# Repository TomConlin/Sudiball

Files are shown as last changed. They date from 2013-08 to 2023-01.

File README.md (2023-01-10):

Sudiball
========
# Sudiball
## Skeletal ball and socket  
### It's like a ball but less.   

To play with the models yourself you will need to  
install a recent __stable__ version of OpenSCAD  
(You may need to get a recent version from <http://www.openscad.org/>)

I am focusing this software on easily built "standard" versions  
(where the planes intersect at right angles in the center of the ball).   
To facilitate visual experimentation prior to generating 2D or 3D files,   
the OpenSCAD scripts are divided into four modules.

__sudiconfig.scad__: Where you will edit parameters (use any text editor)   
__sudiview.scad__:	 Open with OpenSCAD to see changes from parameters edited & save 3D.  
__sudigen.scad__:	 Open with OpenSCAD to generate 2D parts seen in sudiview  
__sudilib.scad__:	Common routines used by both sudiview & sudigen.   

Workflow is: with all four files in the same directory:  
1.  open the _sudiconfig.scad_ file in your favorite text editor  
  (you can also use OpenSCAD as your editor but will need to switch files more  
2.  open __sudiview.scad__ in OpenSCAD and have it render (hit F5)  
3.  Edit the _sudiconfig.scad_ file to suit your needs  
4.  Hit F5 to render your changes in the OpenScad window running sudiview.scad_  
5.  Rinse and repeat the previous two steps to your hearts content  
6.  For 3D files just choose the format you want (.stl) and __Export__ it.  
7.  For 2D files of one flat sheet use __sudigen.scad__ and read instructions.  

------------------------------------------------------------------------
For more information see:
  
- My page with other ATM related
https://ix.cs.uoregon.edu/~tomc/Hobbies/Astronomy/ATM/index.html  
 
- A short informal paper
http://ix.cs.uoregon.edu/~tomc/Hobbies/Astronomy/ATM/SudiBall.pdf

- Initial set of vector files (circa 2013)  
[SVG,DXF,PDF](vector_files/)  
[Initial OpenSCAD SudiBall Template](Mark_I/sudiball_template.scad/)

------------------------------------------------------------------------
Occasional Updates with newer further down the page  
--2013 Jul

In the spirit of moving from the theoretical "you can design anything you want" 
to the more practical -- this is the simplest Sudiball to build with everyday tools and materials. 

CAD drawings and print files of my first generic Sudiball are in the [Vector Files](/vector_files/) directory. 
There are two sizes of vector drawing and four formats in the
Both are designed to use 3/4" material. 
So far, the 24" has been scaled in half and used with 3/8" material 
and to a third to use 1/4" material. 

The Postscript can be printed on paper glued to whatever and cut out for quick tests 
the DXF may need some cleanup before feeding to a machine, i.e cross-hairs removed.
The important part here is the slots are just 90 degree cuts 
and cutting the entire profile at 90 degrees does not interfere 
with making the compound curve on the runners as a separate operation. 
This means the profiles may be cut with a laser, waterjet, CNC router, milling machine 
or by hand with a router or saw.

The compound curve on the runners of a two foot diameter Sudiball with a 3/4" thick edge 
is under six thousandths of an inch, since the square edge is tangent to the sphere. 
This means just breaking the edge with sandpaper does a pretty good job of forming the desired curve.
i.e. Sticking adhesive back sandpaper to the ground ring and swirling it about is enough.

--------------------------------------------------------------------------------

--2017 March  
A couple of incremental update notes.  
First regarding a base which can be a simple ring.  
The SudiBall must contact the ring in at least three places which limits the
diameter of the supporting ring to be not smaller than
the height of the triangle formed by the intersecting runners.
(height is measured from the center of the base to the apex of an equlateral triangle)  
This give a rule of thumb of the diameter of the contact patch on
the support ring not less than 61.25% of the SudiBall diameter.

If you care where the 61.25% comes from,  
the length of a chord with 90 deg separation is:  
`2 *sin (90/ 2 ) * r`

three of those chords come together as a equilateral triangle  
the height of an equilateral triangle is  
`sin(60) * length of a side`  
since we want a precentage of a unit diameter and not of a unit radius
we can drop the leading `2 *`

`sin(45) ×sin(60)  = 0.612372436`  
`0.612372436 * 100 = 61.25%`
 
------------------------------------------------------------------------------
second note:   
It is easy to unedrestimate the lateral forces in play which to tend to distort
the ring from circular to a trifoil or warped from a plane.
Even small distortions will cause a _TIC!_ when a runner contacts the support ring broadside.

Two approaches to mitigate the _TIC!_.  
- Use a stronger ring support.  
- Ease the approach onto the support.  

The first needs whatever works, the second is geometery.  
If the support surface is flat and nearly _normal_ or _tangent_ to the curve
of the SudiBall it forms little "on ramps" whos easement is related to 
the the width of of the flat surface.  
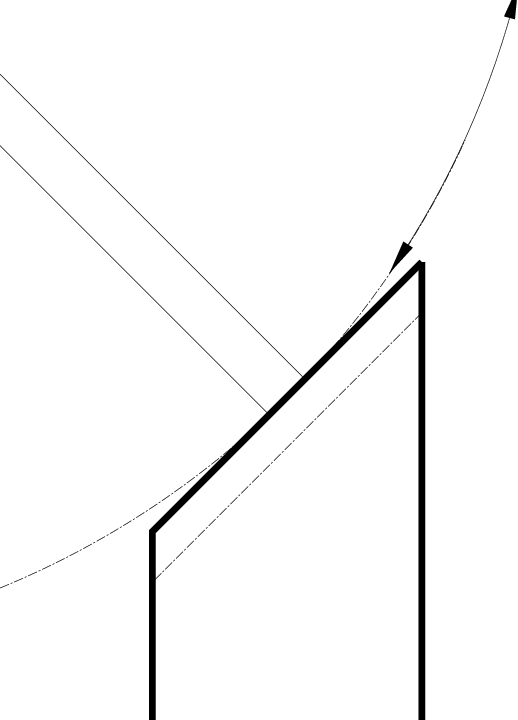
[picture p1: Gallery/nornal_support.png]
conic easement


It also allows covering the support surface with a (_replacable_)   
sheet material i.e. metal or fancy plastics cut into a strip with a [Cone Calculator](https://duckduckgo.com/?q=cone+calculator&ia=web)

With a slightly larger than minimal sized ring for a standard three plane SudiBall  
an off-the-shelf [45-deg router bit](https://duckduckgo.com/?q=45+deg+router+bit+chamfer&iax=1&ia=images)
swung in a [router compass jig](https://duckduckgo.com/?q=router+compass+jig&iar=images&iax=1&ia=images) will chamfer
a nearly normal support surface.  

------------------------------------------------------------------------------

Joining the tips of a sudiball together can be tricky if joinery is not also your day job
but by cutting interlocking fingers into the ends of the runners you get a
simple solid connection called a [fingerjoint](https://en.wikipedia.org/wiki/Finger_joint)  
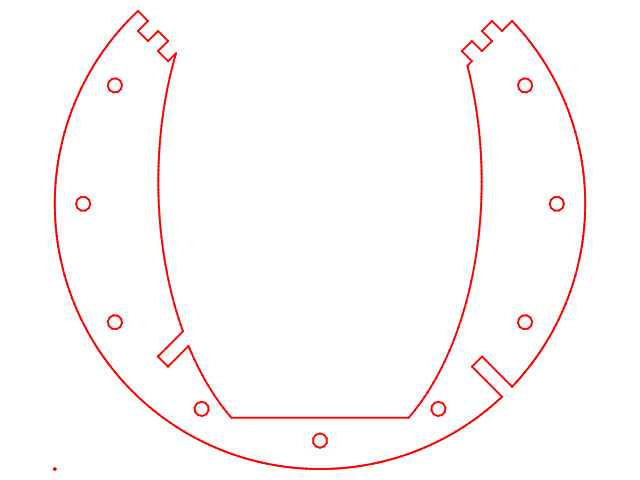
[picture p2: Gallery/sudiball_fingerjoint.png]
fingerjoint
  
(which is especially trivial if you are using  CNC with negligible kerf)

-------------------------------------------------------------------------------
-------------------------------------------------------------------------------

If you have build a SudiBall, please do get in touch,

I have set up a [Rouges Gallery](https://ix.cs.uoregon.edu/~tomc/Hobbies/Astronomy/ATM/SudiBall/RoguesGallery/index.html) and would be happy to show or point your work.

The annotated gallery is currently set up to accept jpeg images  
along with an optional separate simple text (.txt) file per image.  
(same filenames, diferent extensions)

Email sudiball360@gmail.com for more info.

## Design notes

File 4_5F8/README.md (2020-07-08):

There many unloved 4.5" (114mm) f8 Newtonion telescopes out there on rickety tripods. 


Pushed each holliday season then closeted till the garage sale when the novelty of fiddeling with setting it up wears off.  

Now a days they get trumped up with "GoTo" moters for double extra fiddelness and a coresponding disapointment with 
what is charitably, a binocular scale view with poor eye relief and awkward handeling.  

We can't change the optics, but by mounting as a Sudiball we can eliminate fiddeling with the spindley tripod 
and improve the ergomomics for viewing (especially for child sized humans).

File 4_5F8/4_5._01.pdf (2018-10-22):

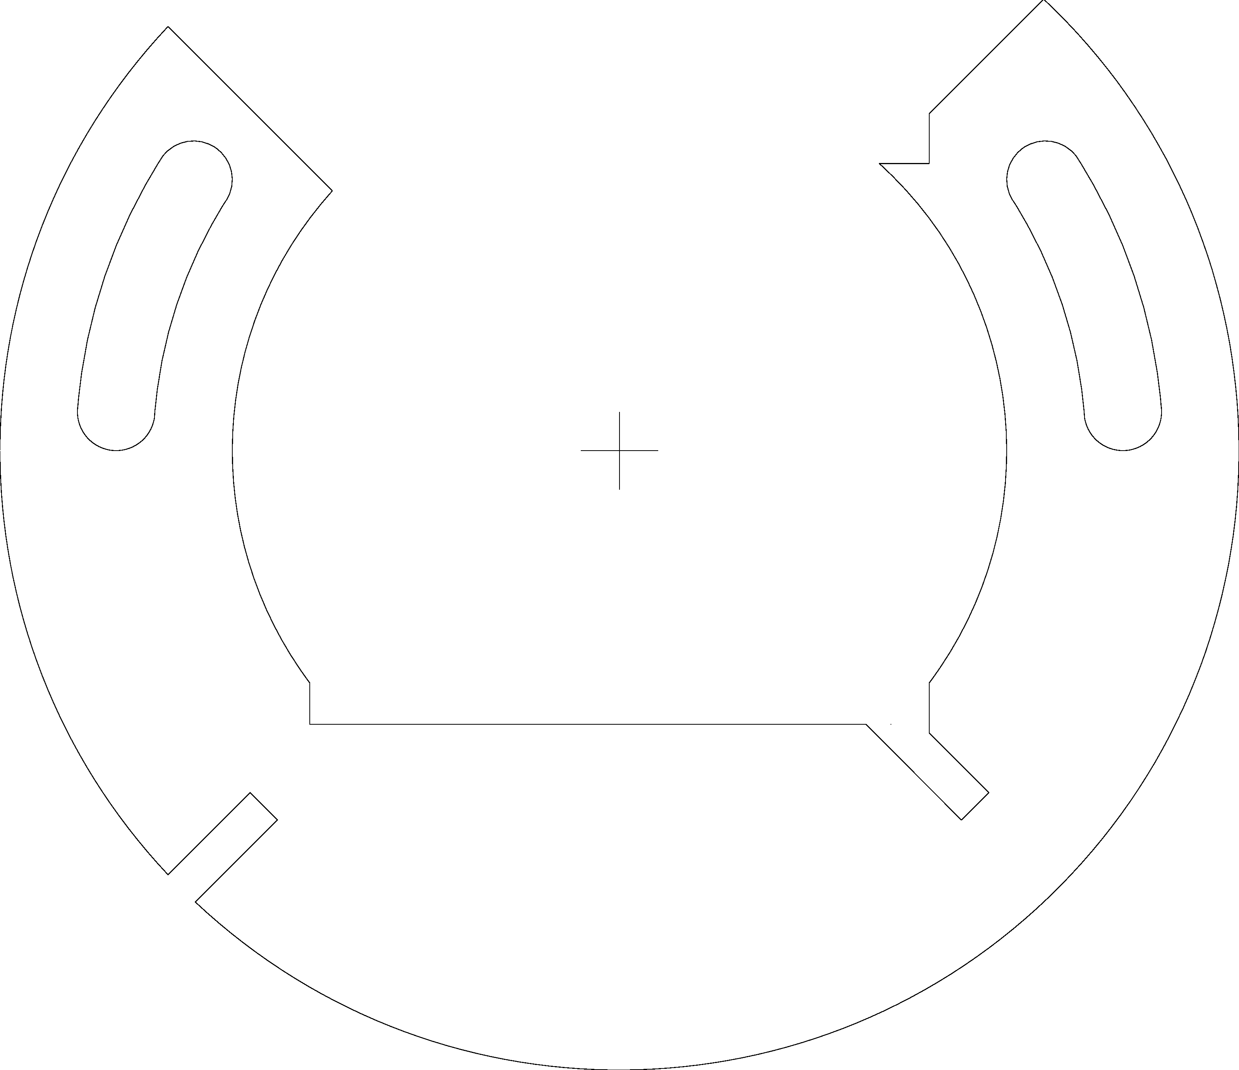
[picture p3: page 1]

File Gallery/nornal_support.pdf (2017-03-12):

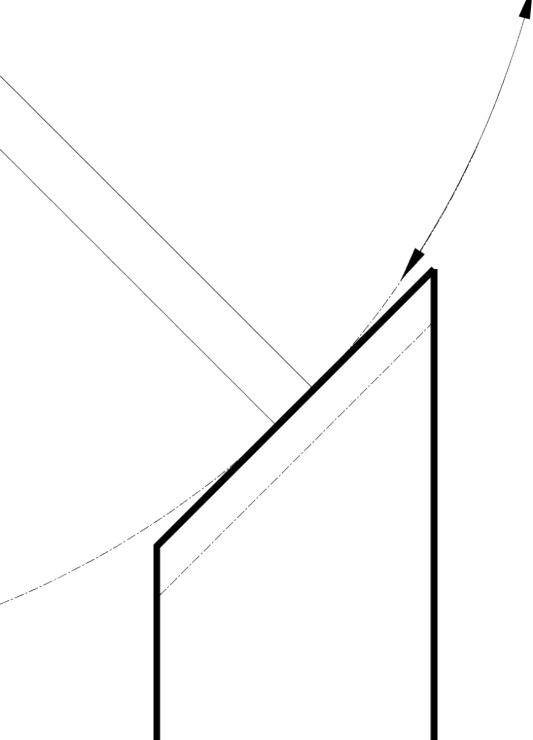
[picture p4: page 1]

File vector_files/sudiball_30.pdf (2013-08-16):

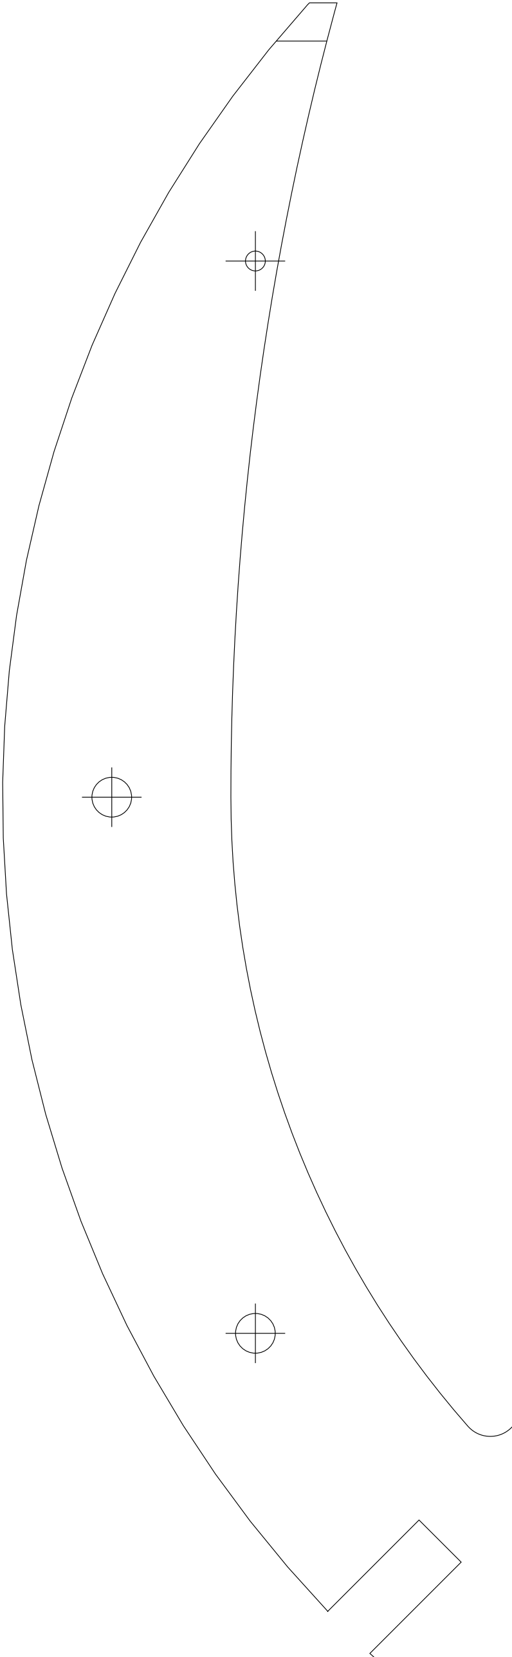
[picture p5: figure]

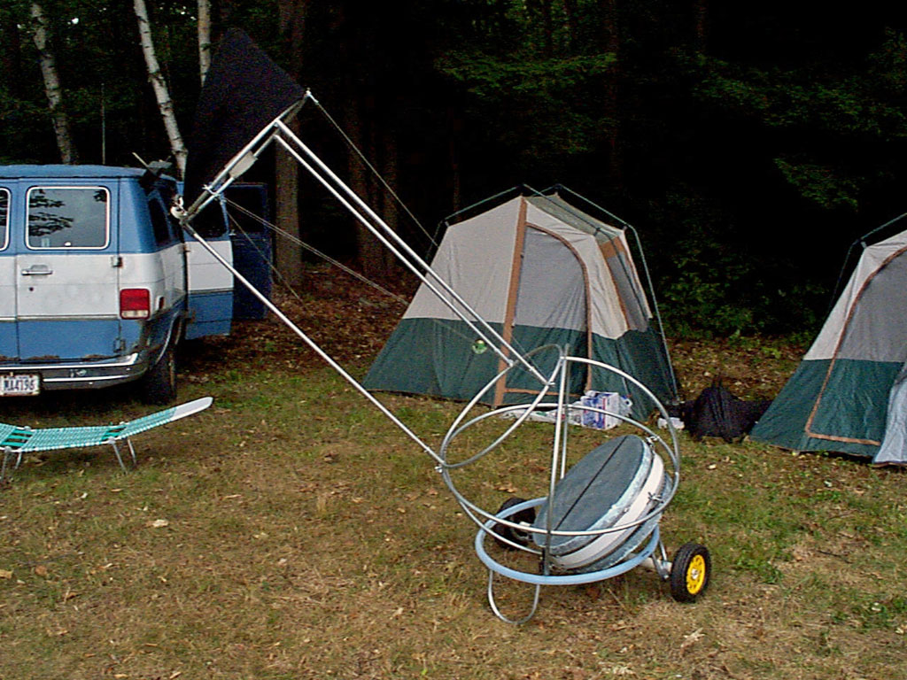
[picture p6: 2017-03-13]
Gallery/Stelafane_1999_via_Pierre_Lemay.jpg

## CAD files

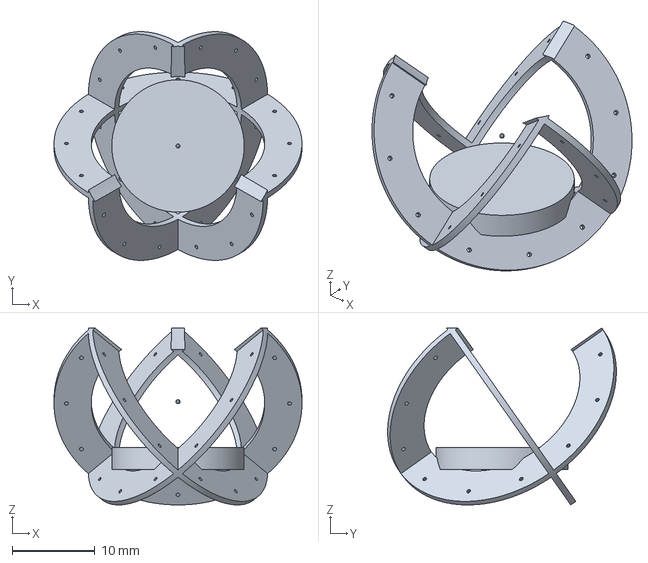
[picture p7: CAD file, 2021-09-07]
16_F4.5/16F4_5.3mf
30.0 x 27.7 x 21.4 mm

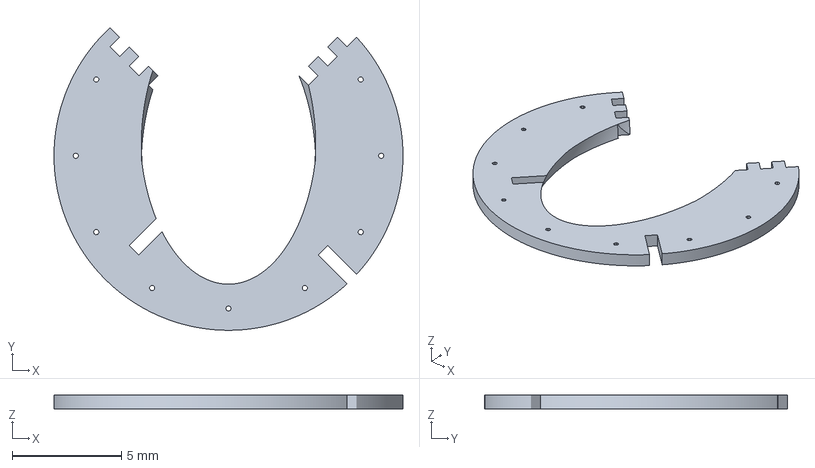
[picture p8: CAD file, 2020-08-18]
4_5F8/gen_panel_section.3mf
16.0 x 13.9 x 0.625 mm

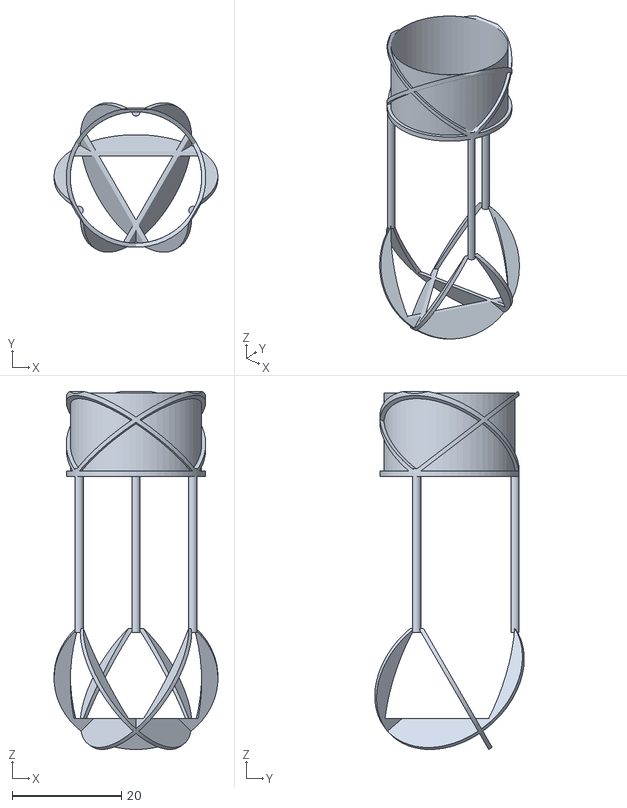
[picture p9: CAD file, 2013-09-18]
OSP_30_2.stl
30.0 x 27.3 x 65.4

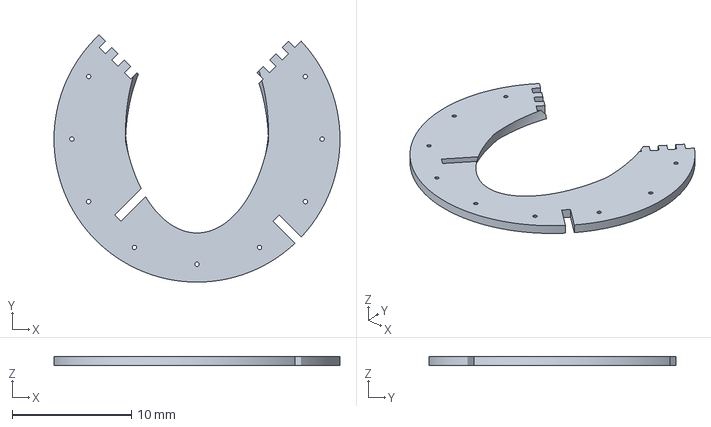
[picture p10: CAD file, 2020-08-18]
sixF8/gen_panel_section.3mf
24.0 x 20.7 x 0.75 mm

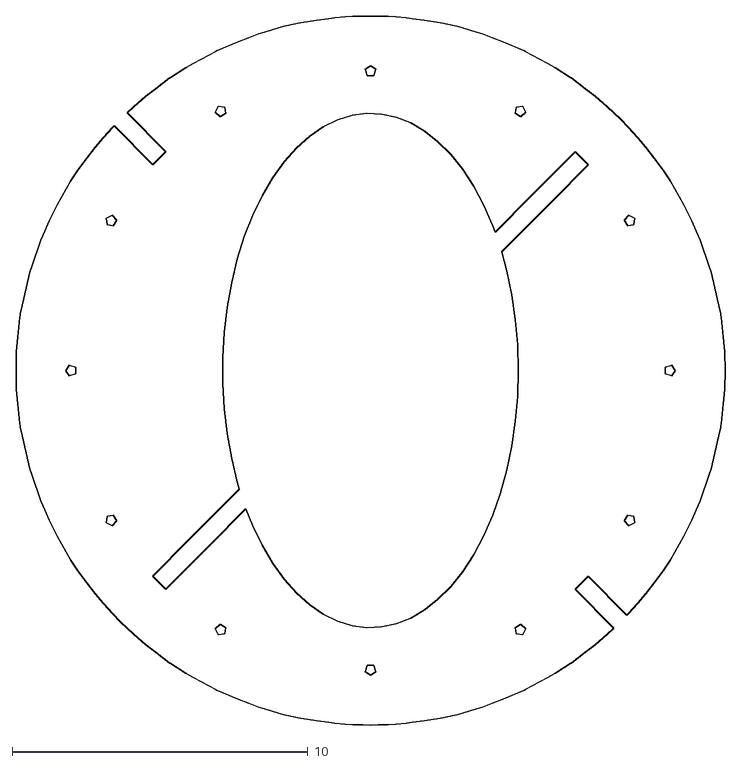
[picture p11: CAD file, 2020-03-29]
TenF4_5/sudigen_10in_path.dxf
24.0 x 24.0

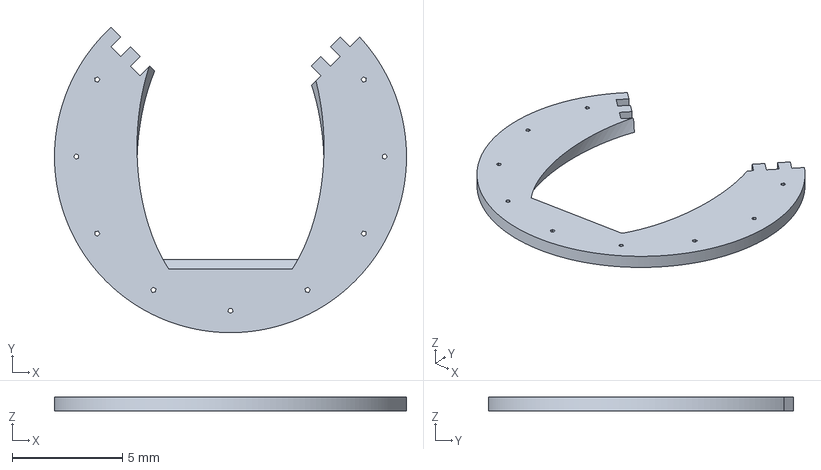
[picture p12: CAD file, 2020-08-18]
Travel_8-F4/travel8f4l_section.3mf
16.0 x 13.9 x 0.625 mm

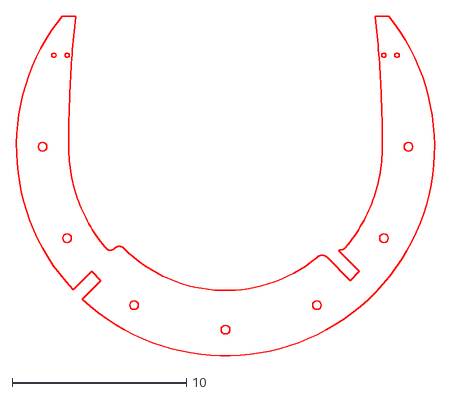
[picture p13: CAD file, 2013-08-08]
vector_files/sudiball_24.dxf
24.0 x 19.5

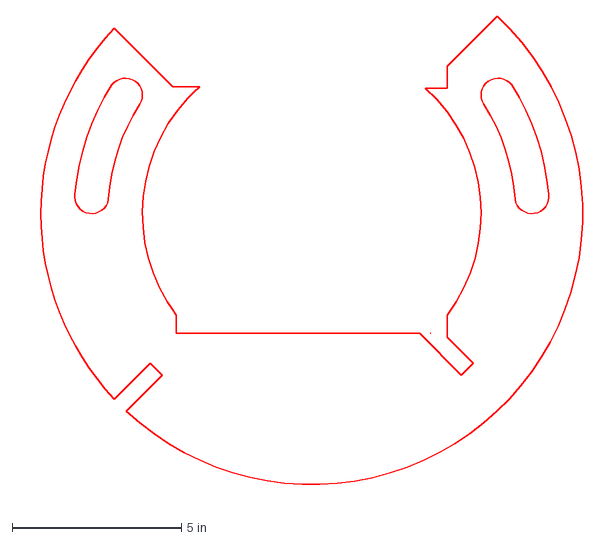
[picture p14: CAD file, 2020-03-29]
4_5F8/4501_resave.dxf
17.2 x 14.3 in

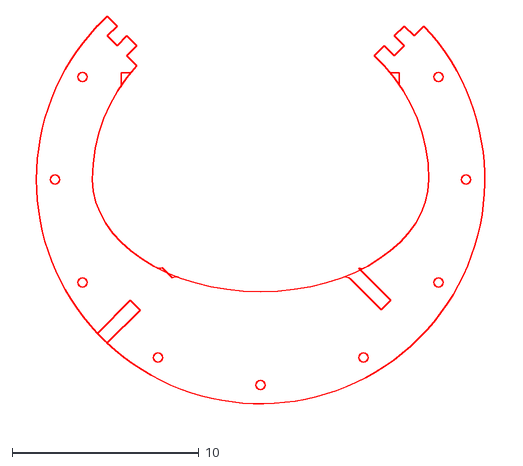
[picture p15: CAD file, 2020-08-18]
sixF8/criterian_tube_holder_print.dxf
26.3 x 21.9

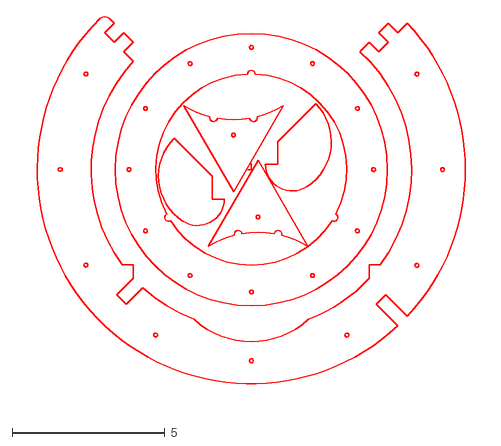
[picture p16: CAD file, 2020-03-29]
TenF4_5/laz1.dxf
15.3 x 12.7

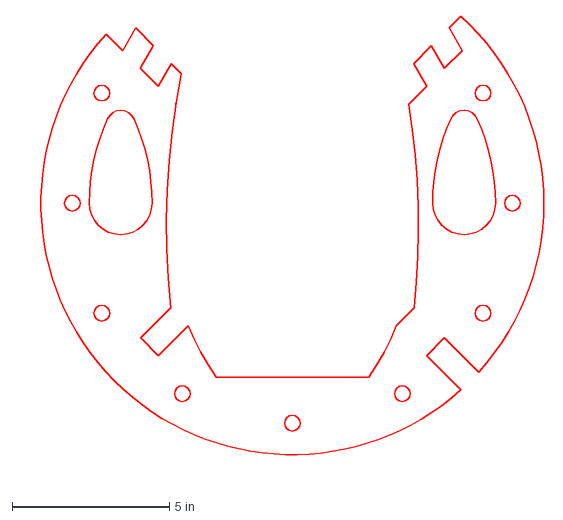
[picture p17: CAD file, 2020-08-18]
Travel_8-F4/#layout3.4.dxf
16.9 x 14.7 in

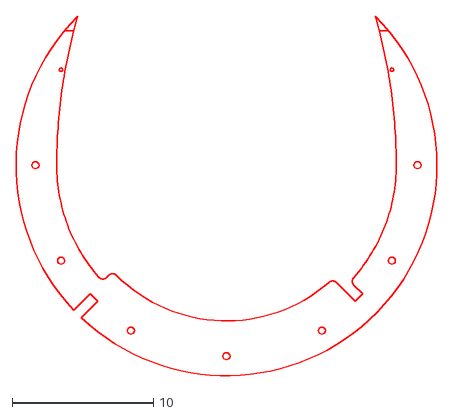
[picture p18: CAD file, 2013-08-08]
vector_files/sudiball_30.dxf
29.7 x 25.4

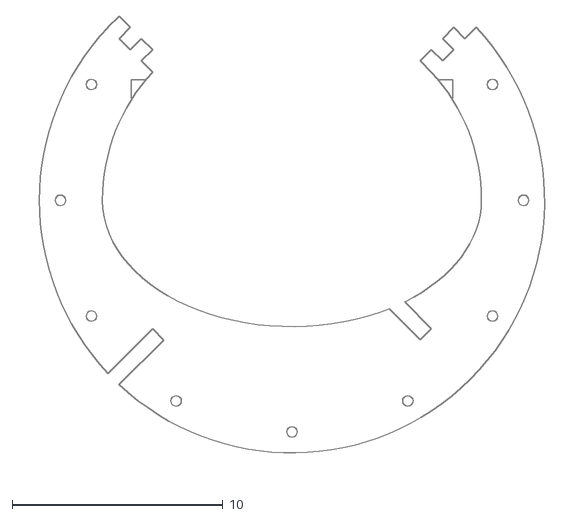
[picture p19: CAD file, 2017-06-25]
sixF8/classic_6in_tube_sudiball_qcad.dxf
26.3 x 21.9

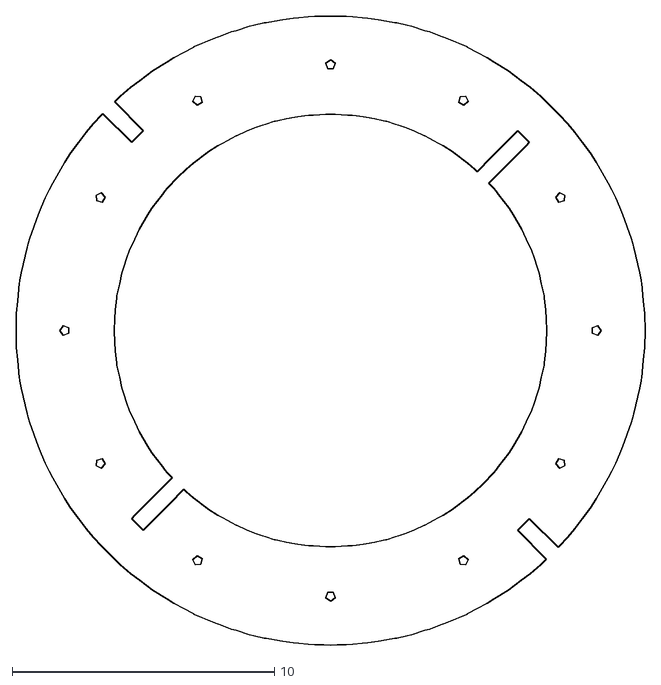
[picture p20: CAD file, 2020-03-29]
TenF4_5/sudigen_6xthick.dxf
24.0 x 24.0

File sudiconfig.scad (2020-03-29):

// SudiConfig
// design parameters to be shared between 3d model generator script
// and the 2D dfx generator script
// KNOWN TO WORK WITH OpenSCAD version 2014.03
// (and seen not working in unstable snapshots)

// bring in the basic helper functions
include <sudilib.scad>;

// magic numbers begin wth '$'
// smaller magic numbers result in slower but smoother curves
// values smaller than .1 are ignored
// make them larger when viewing and smaller when generating if necessary

$fa =	4 ;		   // fragment angle (what looks smooth enough)
$fs =	.5;		// fragment size (using the radius of rouder bit used here)

// mirror amd optical tube assembly (OTA) parameters
ota_id = 8;			// what diameter mirror
F_ratio= 4.0;		// focal ratio (for approximate appearance)

// Sudiball mount design parameters
planes	 =  3;	//  2,[3],4...
tilt	 = 45;	// +/- angles in degrees for the plane

ball_dia = 14;		// what diameter ball to use
thickness = .375;	// sheet material thickness

// hole pattern parameters
// these are holes about the perimeter for fixtures, jigs and whatever
hp_patdia    =	12.5;	// pattern diameter (apx; ball_dia- 4 * thickness)
hp_holedia   =	.375;	// hole diameter
hp_holedepth =	thickness; // hole depth (centered, will add epsilon > 0)
hp_holecount =	12;		// how many holes(would be in full 360 deg)

////////////////////////////////////////////////////////////////////////////////
// derived variables (these should not need to be edited)
intersect =	ball_dia / 2;
ota_ir =	ota_id / 2;
ota_or = ota_ir + thickness;
ball_r =	ball_dia / 2;
delta  =	360 / planes;
centerofrotation = [0,0,intersect];

// to compensate for order of transform operations
relative_tilt =  asin(sin(tilt)) * sin(delta) * 180 / PI;

// may be red herring, but for  45 by 45 
// the above & miter only differ by a half deg
// atan(tan(rot)×cos(tilt))  // miter 
// asin(sin(rot)*sin(tilt))  // bevel

//////////////////////////////////////////////////////////////////////////////
// modules to define shapes used in both sudiview and sudigen

// define the light path clearance to be removed from inside the ball,
// r1 is the light path clearance at the mirror.
// r2 is the clearance some distance above the mirror.
// r2 is not smaller than r1.
// if r2 > r1 then the light path clearance is a cone and 
// the intersection of a cone and inclined plane is a parabola 
// which can be a nice aesthetic.
module lightpath (){
	// the light path won't begin lower in the ball than
	// the dia of the mirror will fit within
    // min height plus whatever is needed to maintain structure or looks.
	translate([0,0,ball_r-sqrt(ball_r*ball_r-ota_ir*ota_ir)+ 3 *thickness])
		cylinder(
			r1 = ota_ir,	 			            // r1 needs to clear the mirror
			r2 = ball_r - 6*thickness,	// r2 can be whatever works for you
			h  = ball_dia - thickness	// h can be whatever works for you
		);
}

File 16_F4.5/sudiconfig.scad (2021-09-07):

// SudiConfig
// design parameters to be shared between 3d model generator script
// and the 2D dfx generator script
// KNOWN TO WORK WITH OpenSCAD version 2014.03
// (and seen not working in unstable snapshots...)
// updated to work in OpenSCAD 2019.05


// bring in the basic helper functions
use <sudilib.scad>;

// magic numbers begin wth '$'
// smaller magic numbers result in SLOWER but smoother curves
// values smaller than .1 are ignored
// make them larger when viewing and smaller when generating if necessary

$fa =	1;		    // fragment angle (what looks smooth enough)
$fs =	.1;		    // fragment size

// mirror amd optical tube assembley (OTA) parameters
ota_id = 16;		// apx what diameter mirror
F_ratio= 4.5;		// focal ratio (for approximate appearance)

// Sudiball mount design parameters
planes	 =  3;	    //  2,[3],4...
tilt	 = 45;	    // +/- angles in degrees for the plane

ball_dia = 30;		// what diameter ball to use
thickness = 0.75;	// sheet material thickness

// hole pattern parameters
// these are holes about the permiter for fixturing
hp_patdia    =	27;	// pattern diameter (apx; ball_dia - 4 * thickness)
hp_holedia   =	.5;	// hole diameter
hp_holedepth =	thickness; // hole depth (centered, will add epsilon > 0)
hp_holecount =	12;		// how many holes (in a full circle)

// derived variables
intersect =	ball_dia / 2;
ota_ir =	ota_id / 2;
ota_or =    ota_ir + 0 ;  //thickness;
ball_r =	ball_dia / 2;
delta  =	360 / planes;
centerofrotation = [0,0,intersect];

//  relative tilt (to horizontal/vertical)
relative_tilt =  sin(tilt) * sin(delta) * 180 / PI;

// i.e. for three planes tilted 45 degrees  
// sin(45) × sin(120) × 180 ÷ 3.1415926535  == 35.0864 degrees
// complement is: 54.9136 degrees


//////////////////////////////////////////////////////////////////////////////
// modules to define shapes used in both sudiview and sudigen

// define the light path clearence to be removed from inside the ball,
module lightpath(){
  // the light path won't begin lower in the ball than
  // the dia of the mirror will fit within

  // min height plus whatever is needed to look right or maintain structure
	translate([0, 0, ball_r-sqrt(ball_r*ball_r - ota_ir*ota_ir) +3*thickness])
		cylinder(
			// r1 needs to clear the mirror @ contact
			r1 = ota_ir,
			// r2 whatever works, not less than r1
			r2 = ota_ir ,
			// h can be whatever works for you
			h  = ball_dia - thickness
		);
}


// define the light path clearence to be removed from inside the ball,
module lightpath2(){
	// the light path won't begin lower in the ball than 
	// the dia of the mirror will fit within
	
	translate([0,0,  ball_r*(1-sin( acos(ota_ir/ball_r) )) + thickness * 6])
		cylinder(
			// r1 needs to clear the mirror @ contact
			r1 = ota_ir, // - 2*thickness,	
			// r2 whatever works, not less than r1 
			r2 = ota_ir,
			// h can be whatever works for you
			h = ball_dia 
		);	
}
///////////////////////////////////////////////////////////////////////////
//
module tiptrim(){
	translate([0, 0, ball_r + thickness/2])
		cylinder(
			r1 = 0,
			r2 = ball_r * 1.414,
			h  = ball_r
		);
}

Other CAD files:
Travel_8-F4/gen_panel_section.3mf
sixF8/classic_6in_tube_sudibal_sagl.dxf
TenF4_5/laz1.1.dxf
4_5F8/sudiconfig.scad
sixF8/sudiconfig.scad
16_F4.5/16F4_5.stl
16_F4.5/sudigen.scad
16_F4.5/sudilib.scad
16_F4.5/sudiview.scad
4_5F8/gen_panel_section.amf
4_5F8/gen_panel_section.scad
4_5F8/gen_panel_section.stl
4_5F8/sudigen.scad
4_5F8/sudiview.scad
Mark_I/sudiball_template.scad
TenF4_5/dxf_import.scad
TenF4_5/freecad_dxf_to_oscad.scad
TenF4_5/sudiconfig.scad
TenF4_5/sudigen.dxf
TenF4_5/sudigen.scad
TenF4_5/sudiview.scad
Travel_8-F4/dxf_import.scad
Travel_8-F4/freecad_dxf_to_oscad.scad
Travel_8-F4/gen_panel_section.amf
Travel_8-F4/gen_panel_section.scad
Travel_8-F4/gen_panel_section.stl
Travel_8-F4/layout2.1.dxf
Travel_8-F4/layout2.2.dxf
Travel_8-F4/layout2.2_flip.dxf
Travel_8-F4/layout2.4.dxf
Travel_8-F4/layout2.4.nc.dxf
Travel_8-F4/layout2_plns.dxf
Travel_8-F4/layout2_plns_cam.dxf
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

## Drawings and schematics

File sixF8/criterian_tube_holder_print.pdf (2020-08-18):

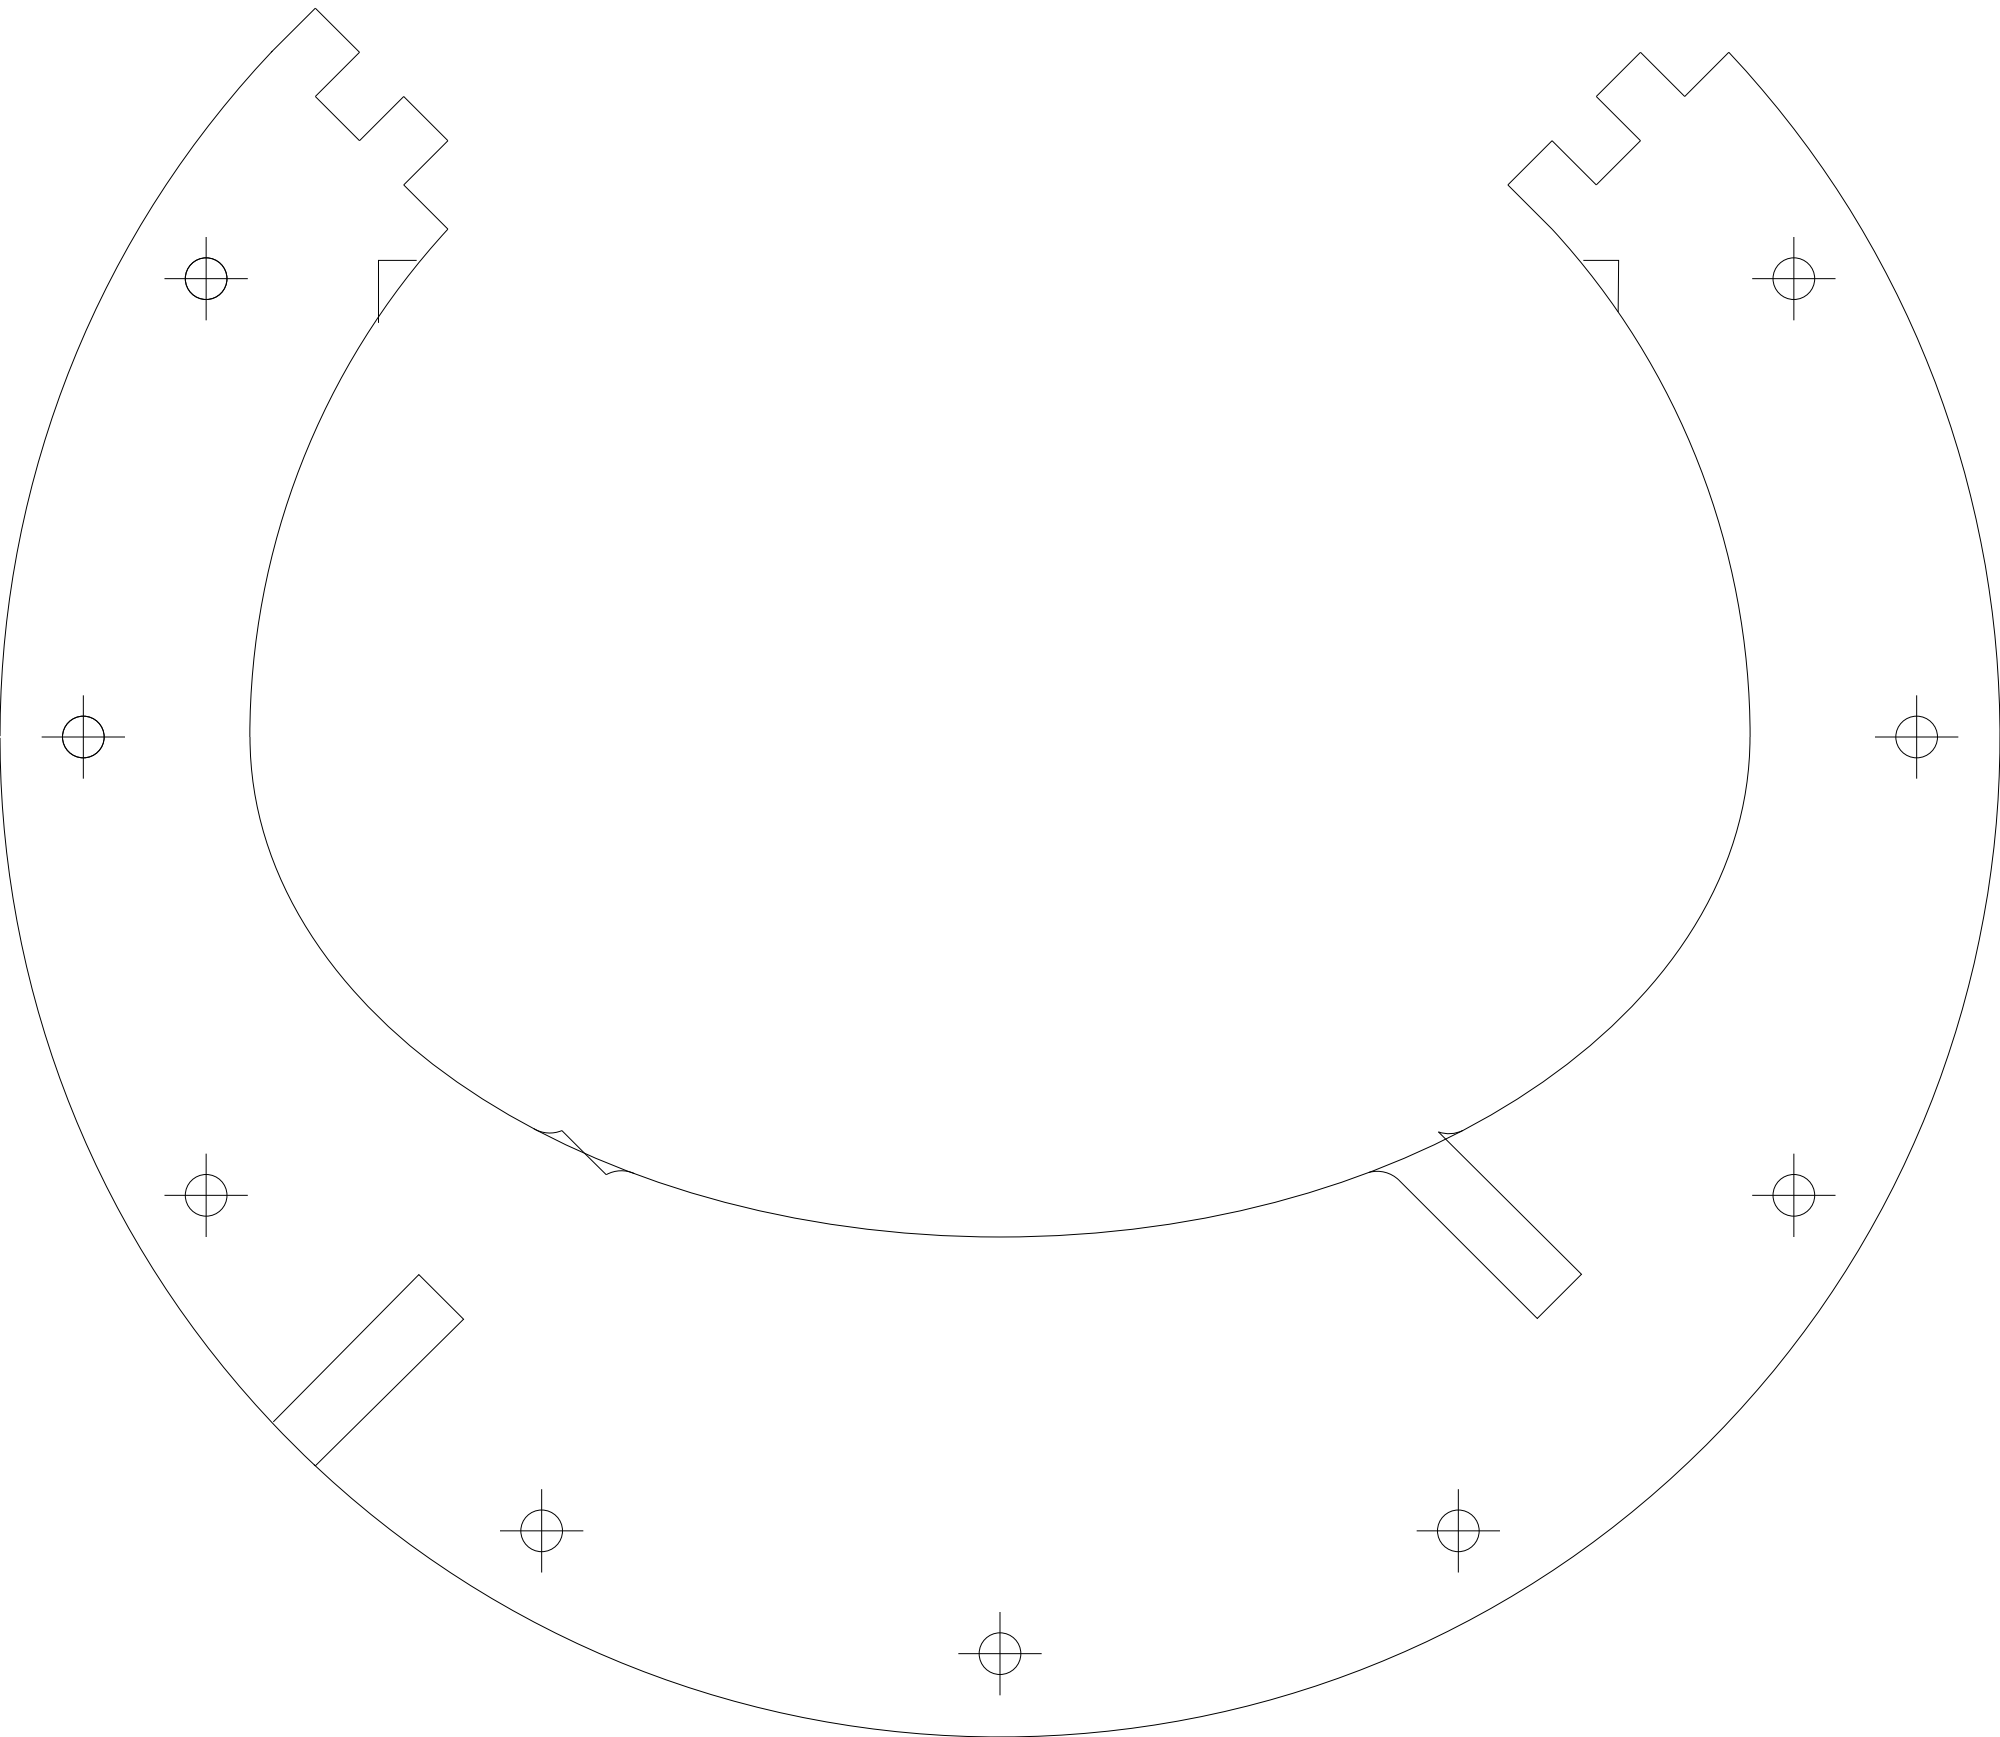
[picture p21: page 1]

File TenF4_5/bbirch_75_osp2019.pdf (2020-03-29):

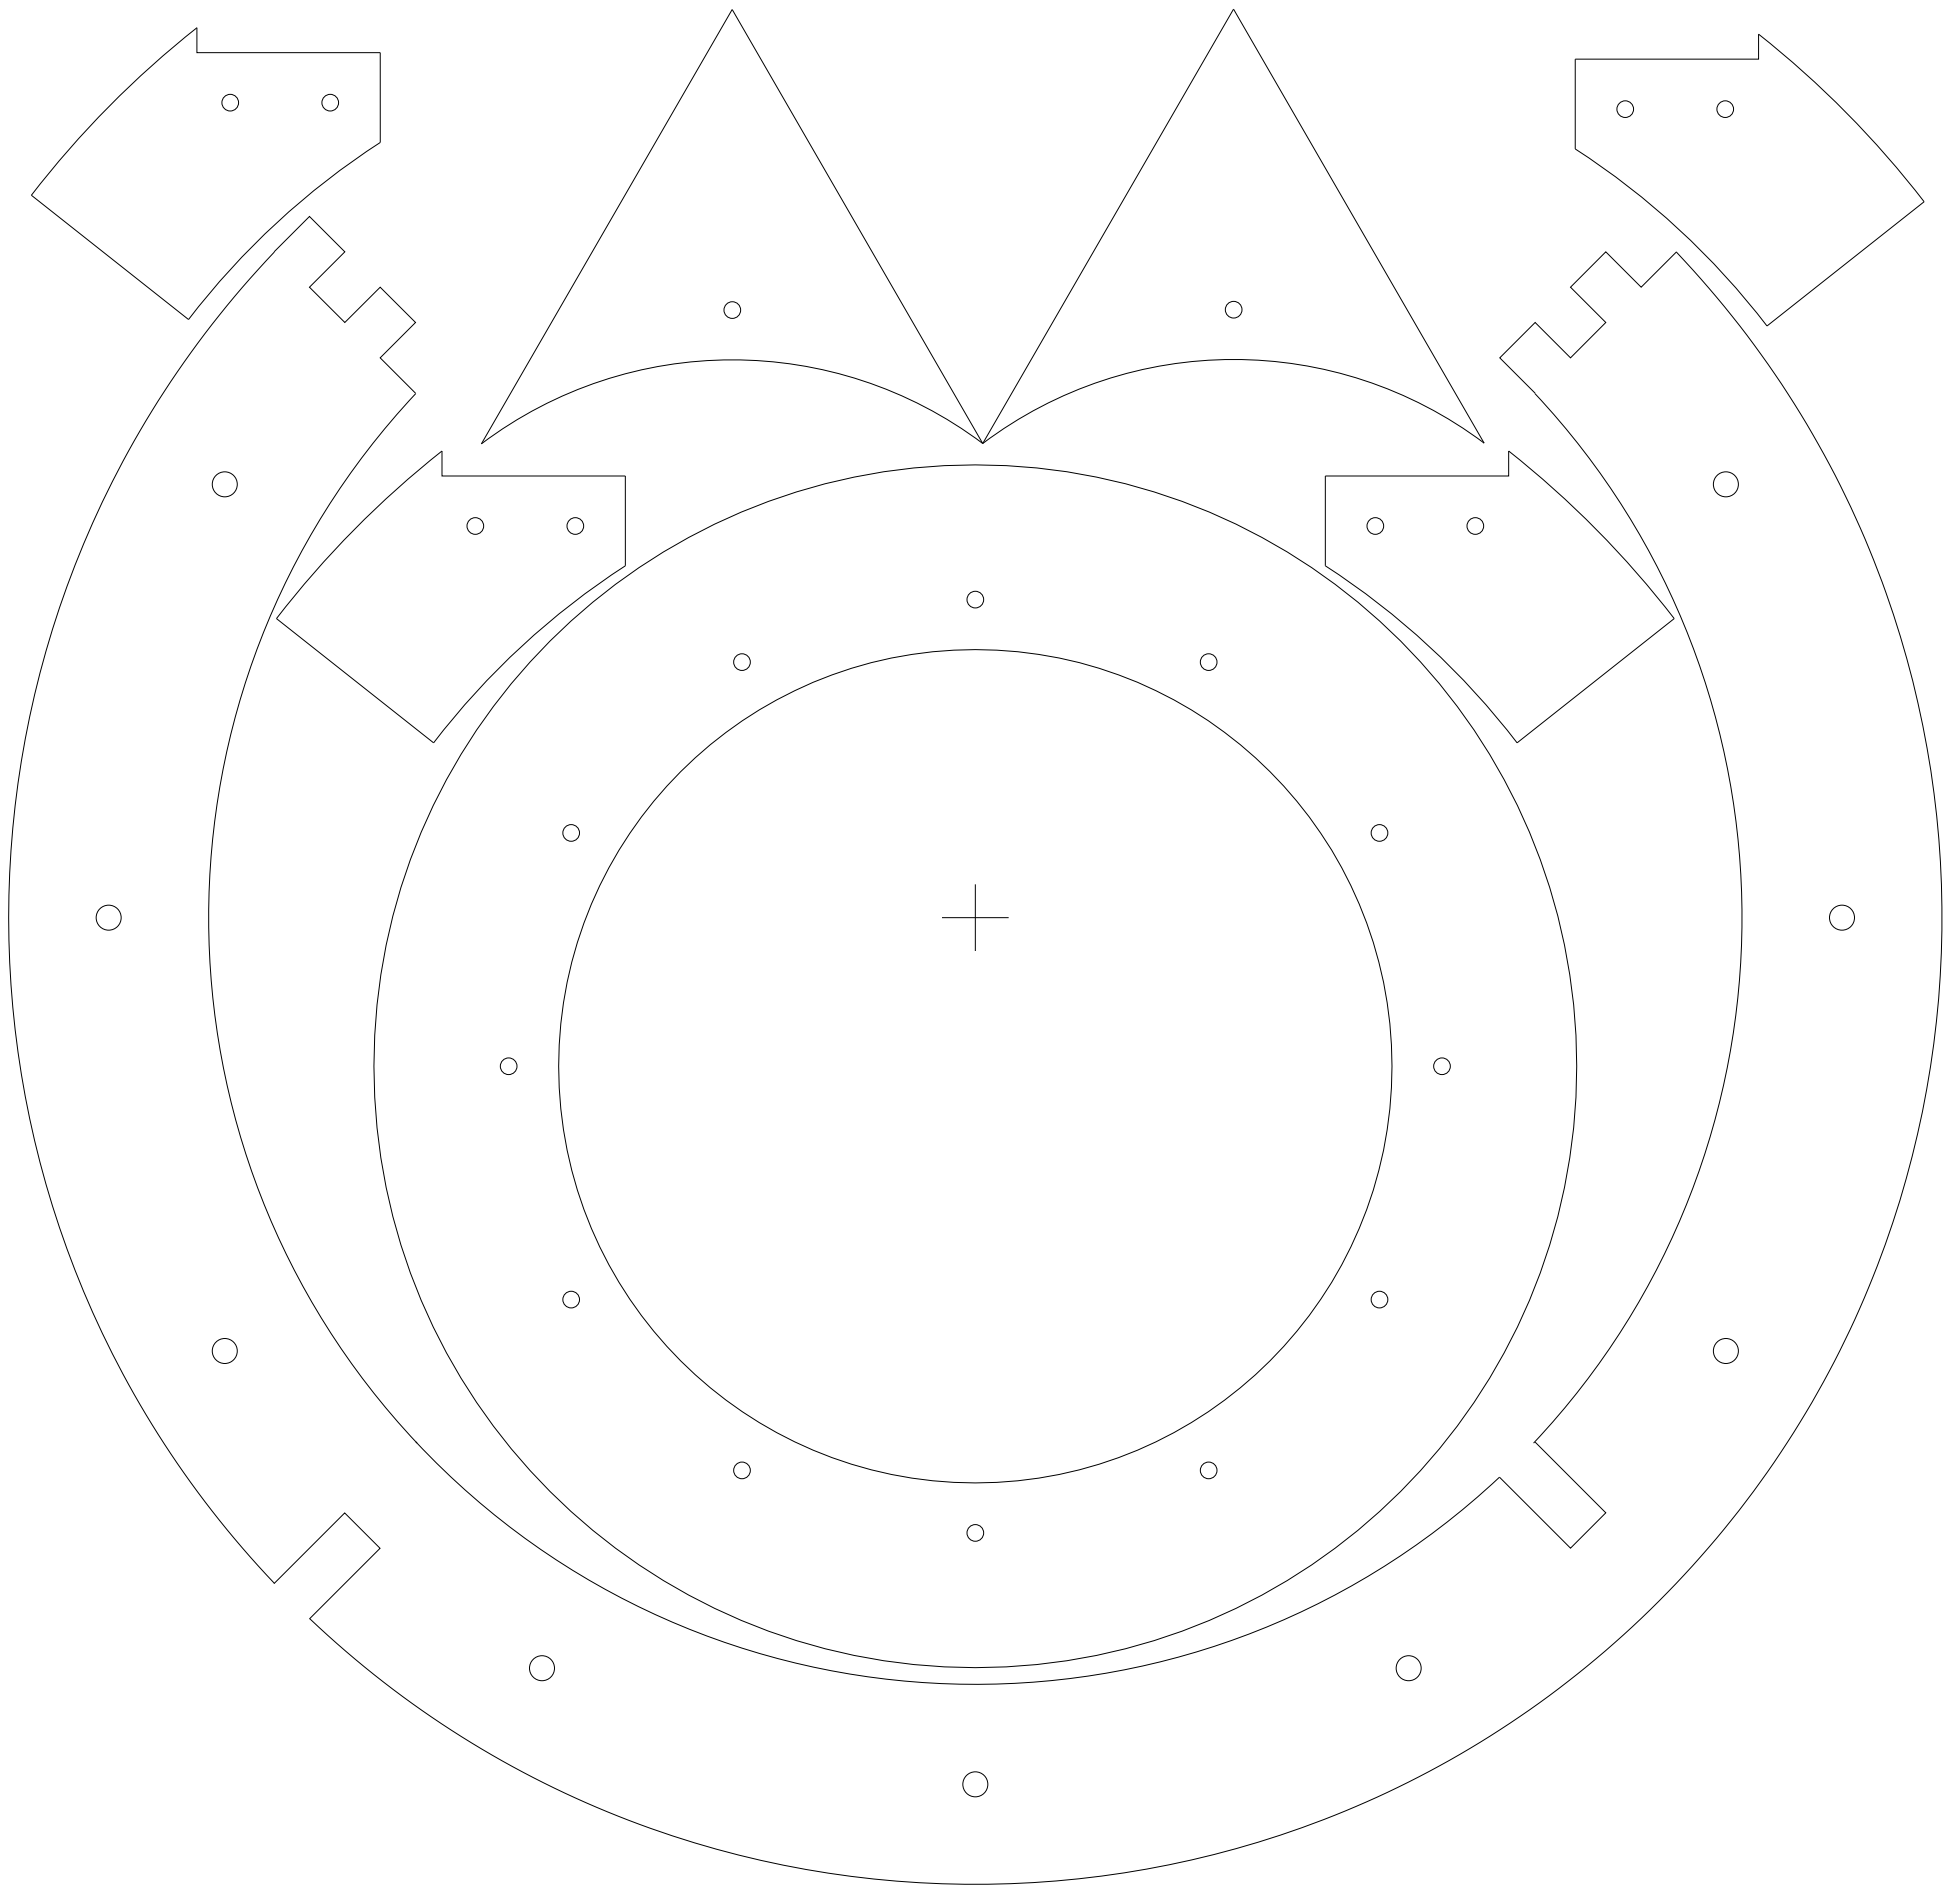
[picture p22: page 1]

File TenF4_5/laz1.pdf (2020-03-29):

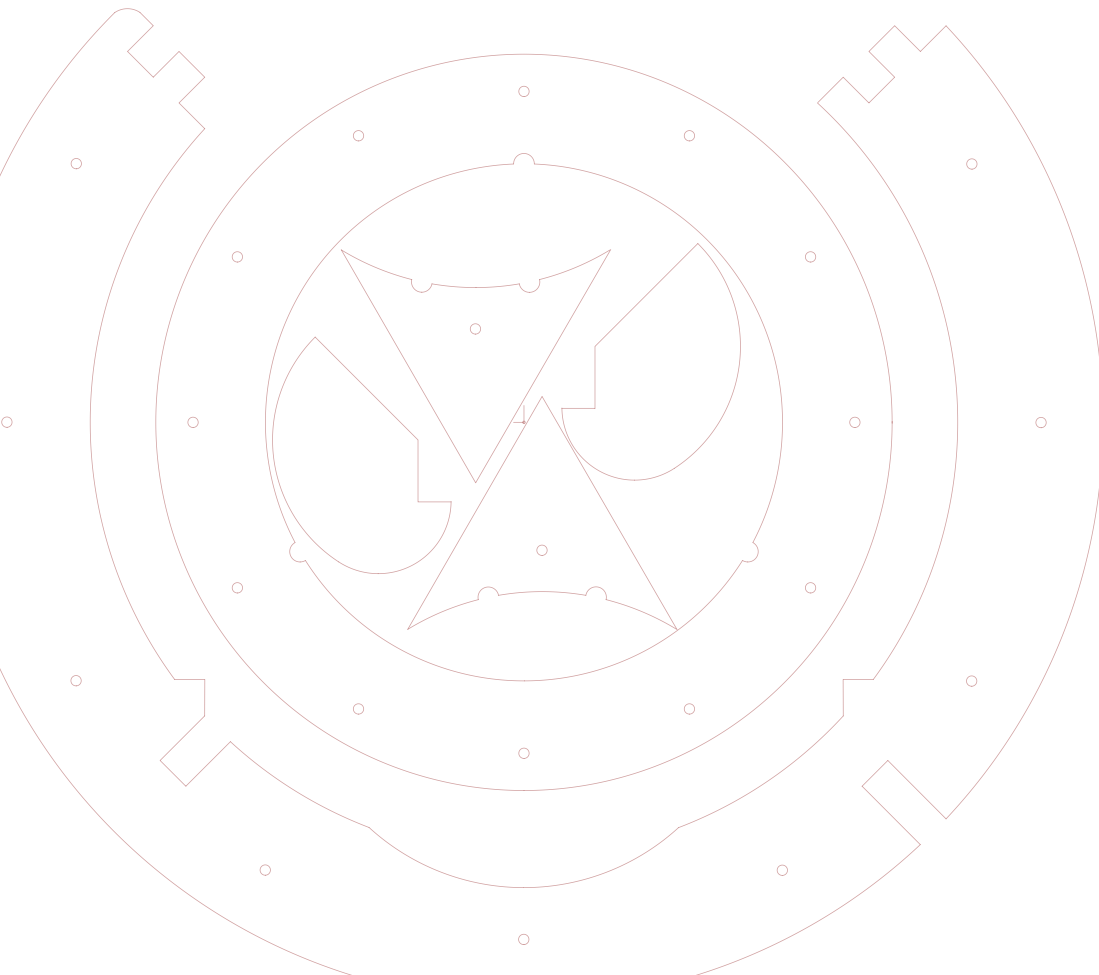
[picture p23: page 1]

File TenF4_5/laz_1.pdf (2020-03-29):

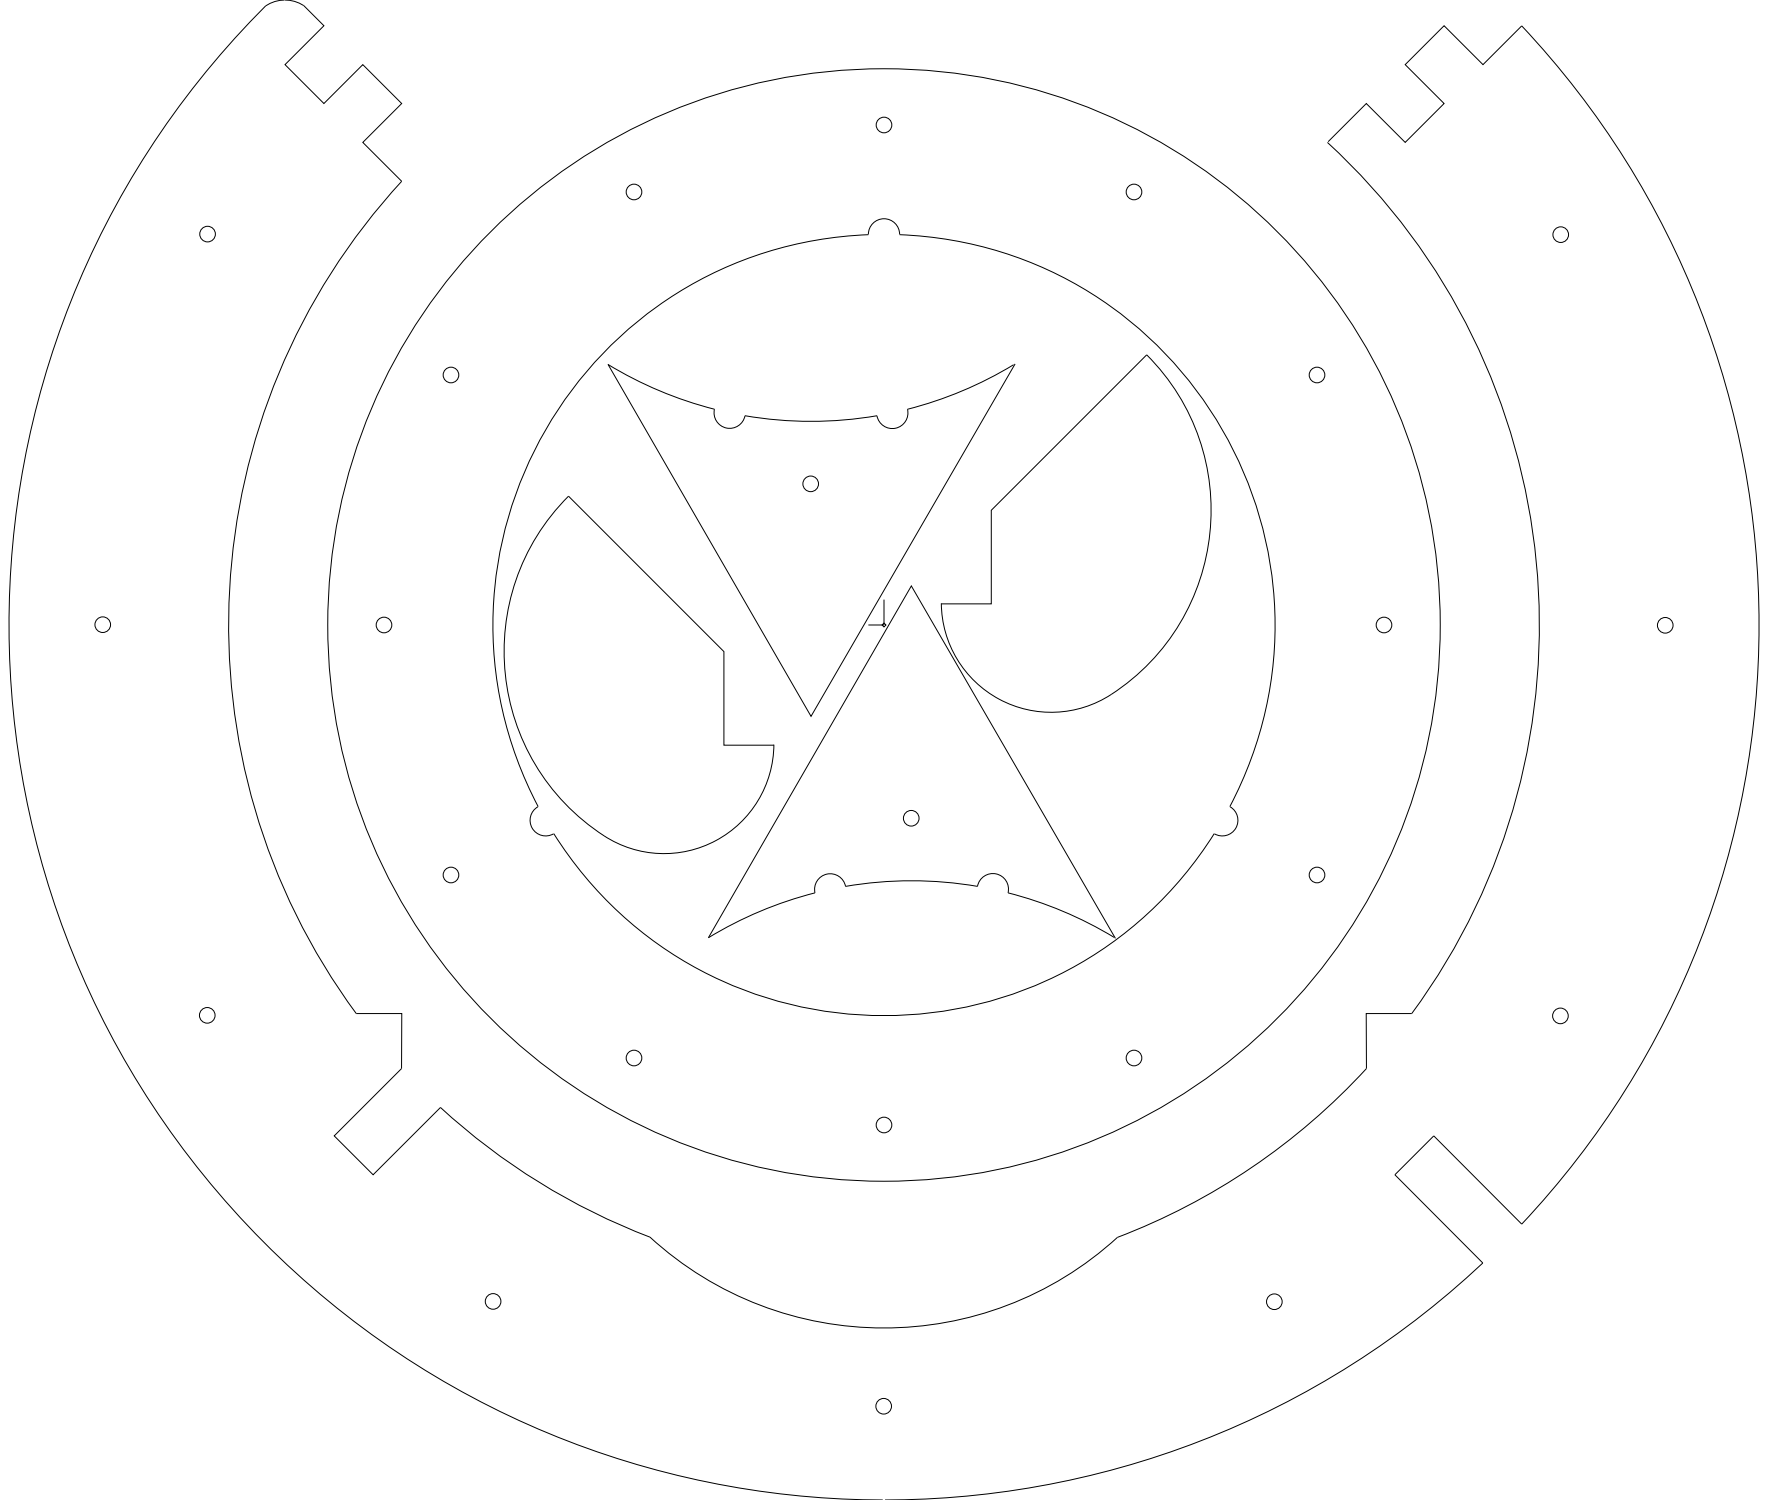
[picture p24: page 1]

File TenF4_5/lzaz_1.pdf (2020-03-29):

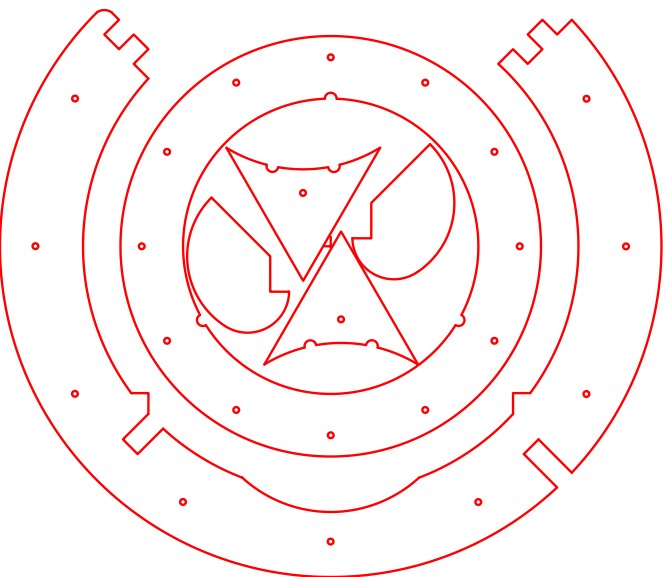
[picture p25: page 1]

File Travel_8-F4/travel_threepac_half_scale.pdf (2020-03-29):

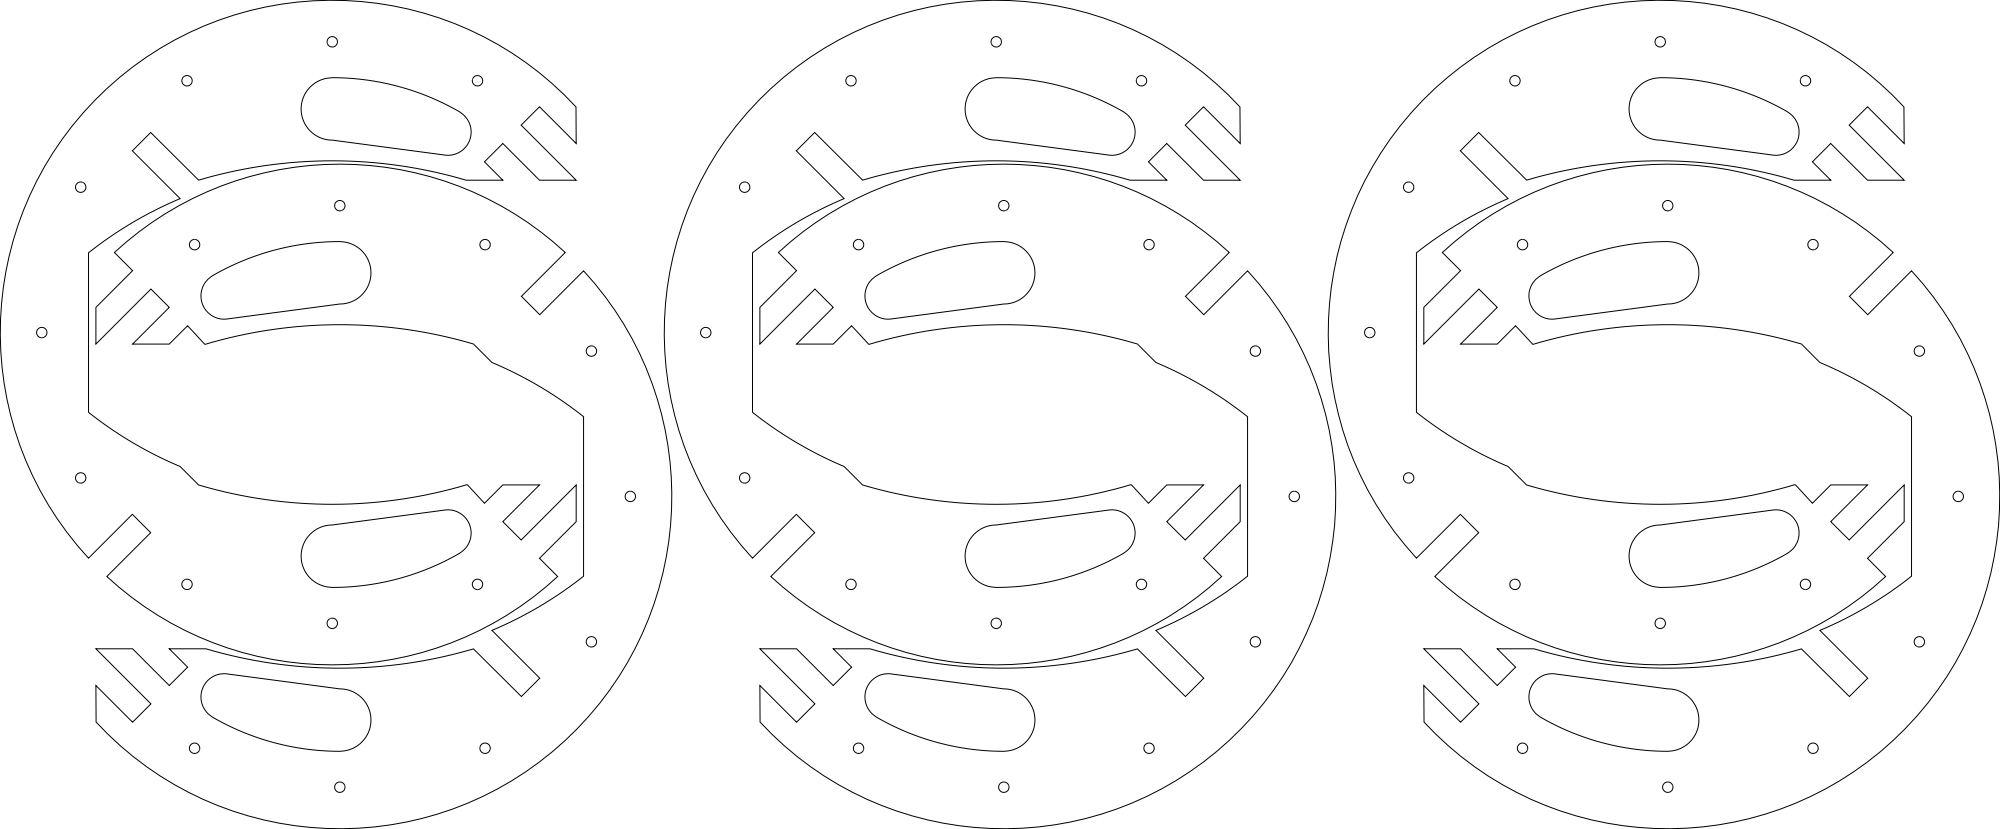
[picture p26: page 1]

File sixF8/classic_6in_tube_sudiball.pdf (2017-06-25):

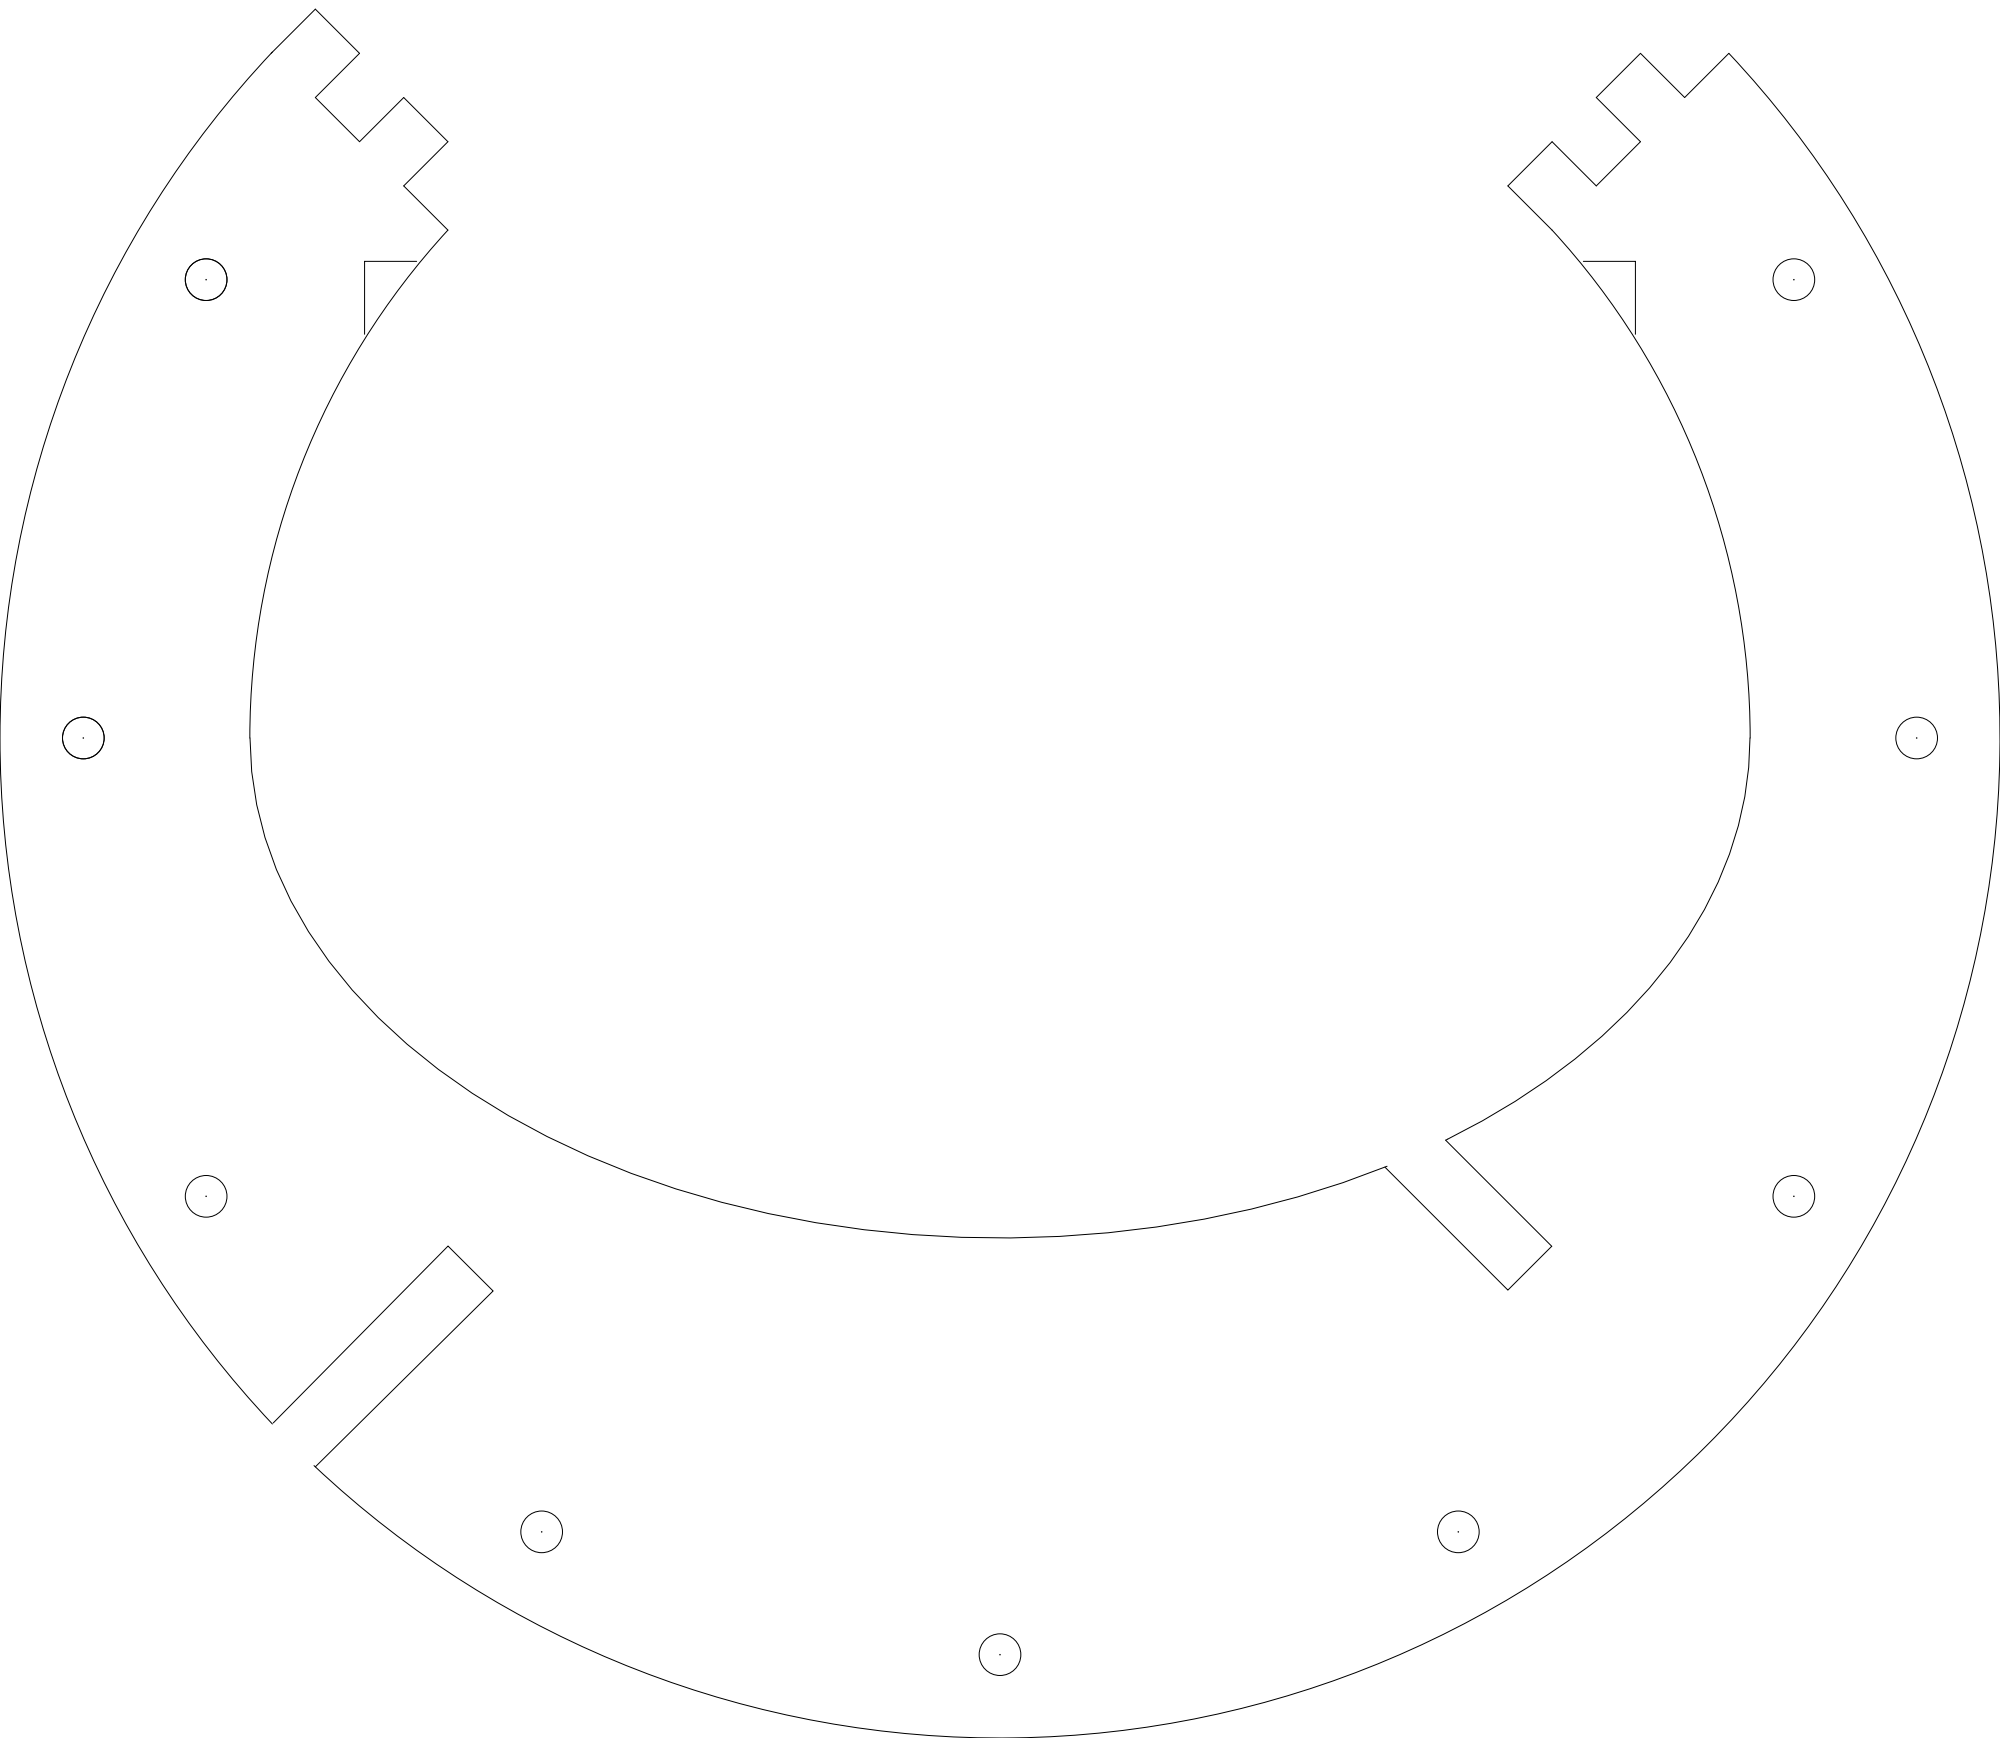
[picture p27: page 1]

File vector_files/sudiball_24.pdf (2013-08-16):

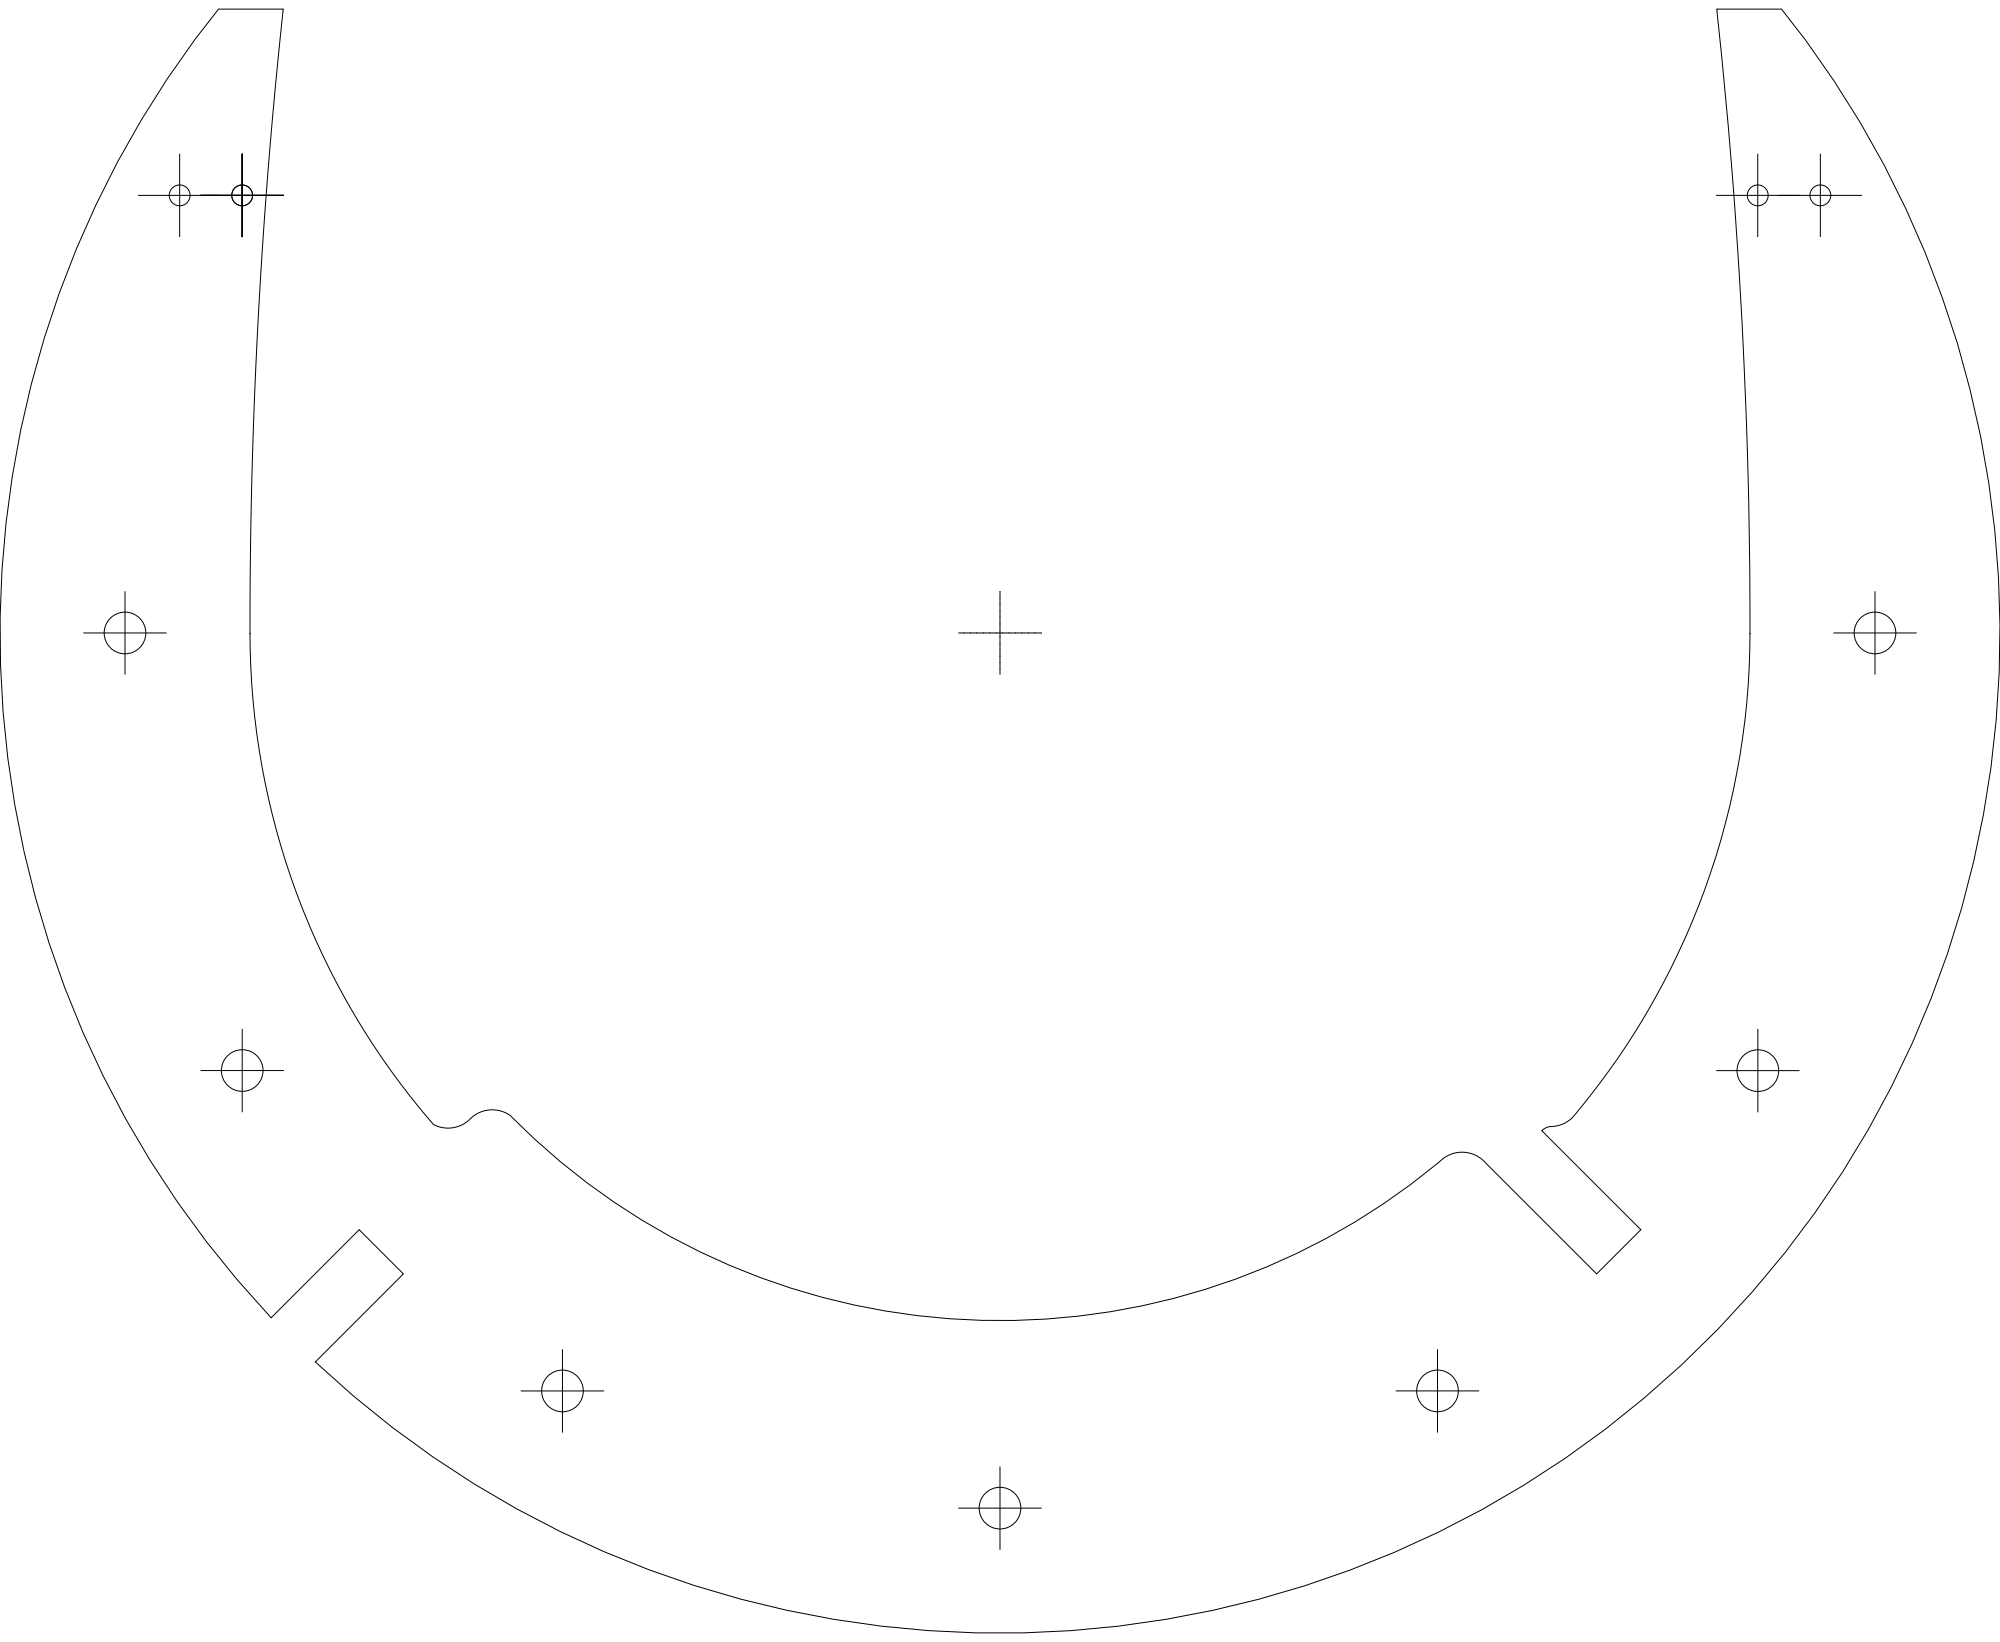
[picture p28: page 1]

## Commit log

2013-08-08 add 2D vector files used to build first instances
    [sudiball_24.dxf, sudiball_30.dxf]
2013-08-16 translate to a couple of more modern formats
2013-09-18 try the 3D model feature
    [OSP_30_2.stl]
2014-05-28 starting a more parametric 2d drawing script
    [sudigen.scad]
2014-05-29 break the monolithic script up into configuration, a library of functions shared by the 3D model generation and the 2D CAD file generator
    [sudiconfig.scad, sudilib.scad, sudiview.scad]
2014-05-29 use the about() fx and center of rotation variable more consistently
    [sudigen.scad, sudiview.scad]
2014-05-31 move hole pattern param to the config
    [sudiconfig.scad, sudigen.scad, sudiview.scad]
2014-06-09 move the lightpath common to both sudigen & sudiview here
    [sudiconfig.scad]
2014-06-09 change call from child() to children() for new version. tried lengthing 'holes' to so they might render better (did not help)
    [sudilib.scad]
2014-06-09 move the lightpath shape to the common config
    [sudigen.scad, sudiview.scad]
2015-01-03 freshen up after a year of bitrot
    [sudiconfig.scad, sudigen.scad, sudilib.scad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]
2015-01-05 move old to Mark I and strt don on Mark II
    [sudiball_template.scad]
2017-03-12 normal support & finger joints
2017-03-12 display fingerjoint
2017-03-28 playing around with long FL left in a tube
    [criterian_tube_holder.dxf, sudiconfig.scad, sudigen.dxf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]
2017-06-25 Sudiball mount vector files for a classic 6 inch F-8 tube scope
    [classic_6in_tube_sudiball.dxf, classic_6in_tube_sudiball_qcad.dxf, criterian_tube_holder.dxf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]
2018-10-22 16 inch sudiball for those nasty hobby killers
    [4_5._01.dxf, sudiconfig.scad, sudigen.scad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]
2018-11-02 add ear on left
    [4_5._01.dxf]
2018-11-02 see if saving from a different prog helps
    [4501_resave.dxf]
2020-03-29 push backlog; just in case it is your turn
    [Plans.cfg, dxf_import.scad, freecad_dxf_to_oscad.scad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]
2020-08-16 new generator process for dynamic panel cutting
    [gen_panel_section.scad, sudiconfig.scad, sudigen.scad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]
2020-08-17 include slots
    [gen_panel_section.scad]
2020-08-17 who knows
    [Plans.cfg]
2020-08-17 moving away from library to standalone script
    [gen_panel_section.scad, sudiconfig.scad]
2020-08-18 bunch of 3d file formats for waterjet
    [#layout3.4.dxf, Plans.cfg, classic_6in_tube_sudibal_sagl.dxf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]
2020-08-18 add 3d vectors for dynamic waterjet cutting
    [gen_panel_section.3mf, gen_panel_section.amf, gen_panel_section.scad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]
2020-08-18 eplison > 0
    [gen_panel_section.scad]
2021-08-28 update for language drift
    [sudigen.scad, sudiview.scad]
2021-09-07 model a 16-inch F4.5; basicly what I did with luceal but with lessons learned
    [16F4_5.3mf, sudiconfig.scad, sudigen.scad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]
2021-09-07 fix depreciated call
    [sudiball_template.scad]
2021-09-10 even less detailed so it can load in GH renderer
    [16F4_5.stl]
